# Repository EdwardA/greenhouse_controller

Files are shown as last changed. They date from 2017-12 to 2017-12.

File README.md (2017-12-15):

# greenhouse_controller
Arduino and Linux based sensor and control network
As part of a belated Devember

This project is to design and implement a distributed sensor and control system to automate an indoors growing environment.

As the network is designed to automate high volume growing enviroments. Each growing bed utalises its own slave unit which manages and records the data from that bed while passing the data back to the main controller for logging. While also reciving data back from the controller to control the actuators on that bed.

The system will be designed to be expandable very quickly and easily, by adding new 'beds' to the network.

---Slave board---

--Sensors--
Light (intensity and colour)
soil moisture
Soil temperature
Air temperature
RTC (Real Time Clock)

--Control--
Growing lights (LED, RGB)
Sprinklers (Three per bed)
Emergancy Stop
Heater

--Conectivity--
USB (mainly for debug and programming)
Ethernet (Comunicating with the controller)

---Controller Board---
Recive sensor data from slave boards, and send changes in paramaters back.
Most likely Python script
ROS?
Recive changes in parameters from user and distribute relevant commands to slave units.

The slave unit is based off the ATMEGA 1284 chip, using a 3rd party arduino bootloader.

The slave is programed thanks to the use of the bootloader found here: http://www.leonardomiliani.com/repository/package_leonardomiliani.com_index.json

Light sensor = TCSP3200, code based off the example given at: https://randomnerdtutorials.com/arduino-color-sensor-tcs230-tcs3200/

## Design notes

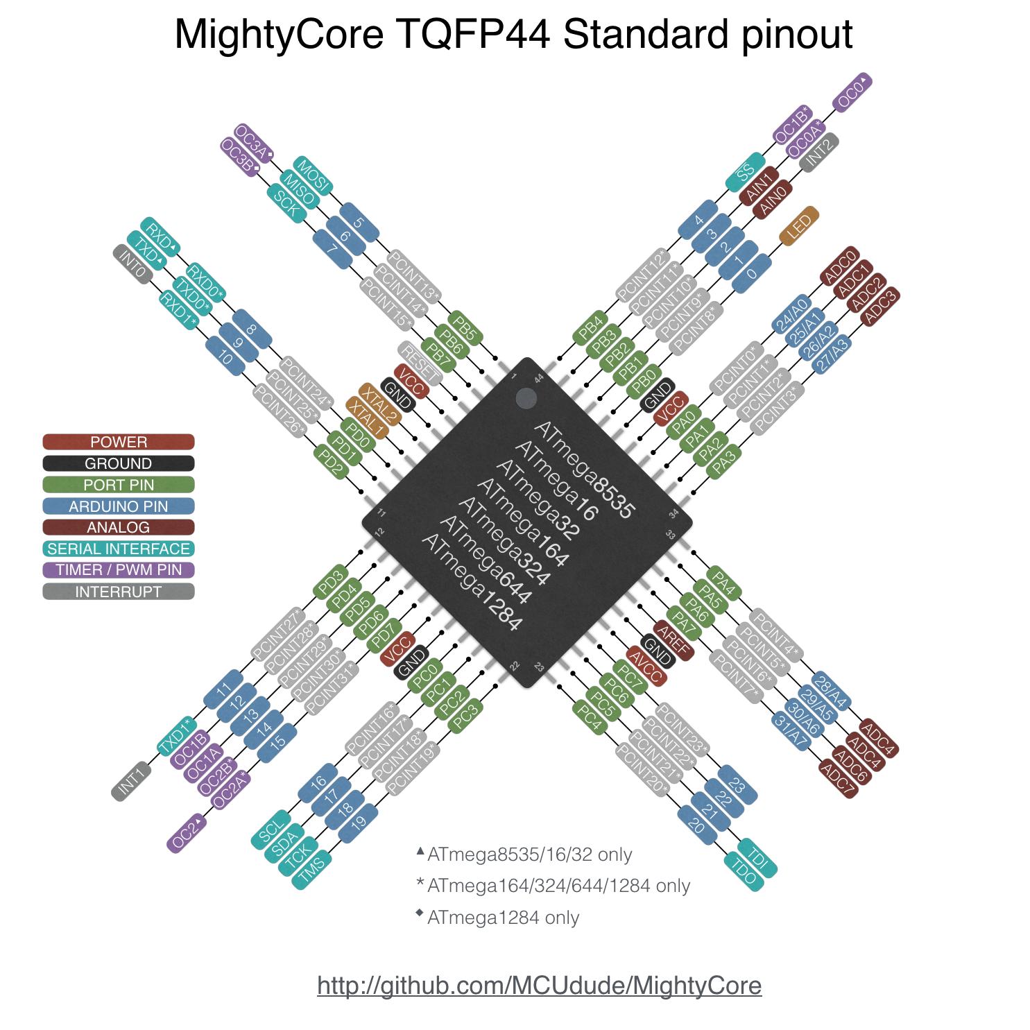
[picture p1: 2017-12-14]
Atmega1284p arduino pinout.png

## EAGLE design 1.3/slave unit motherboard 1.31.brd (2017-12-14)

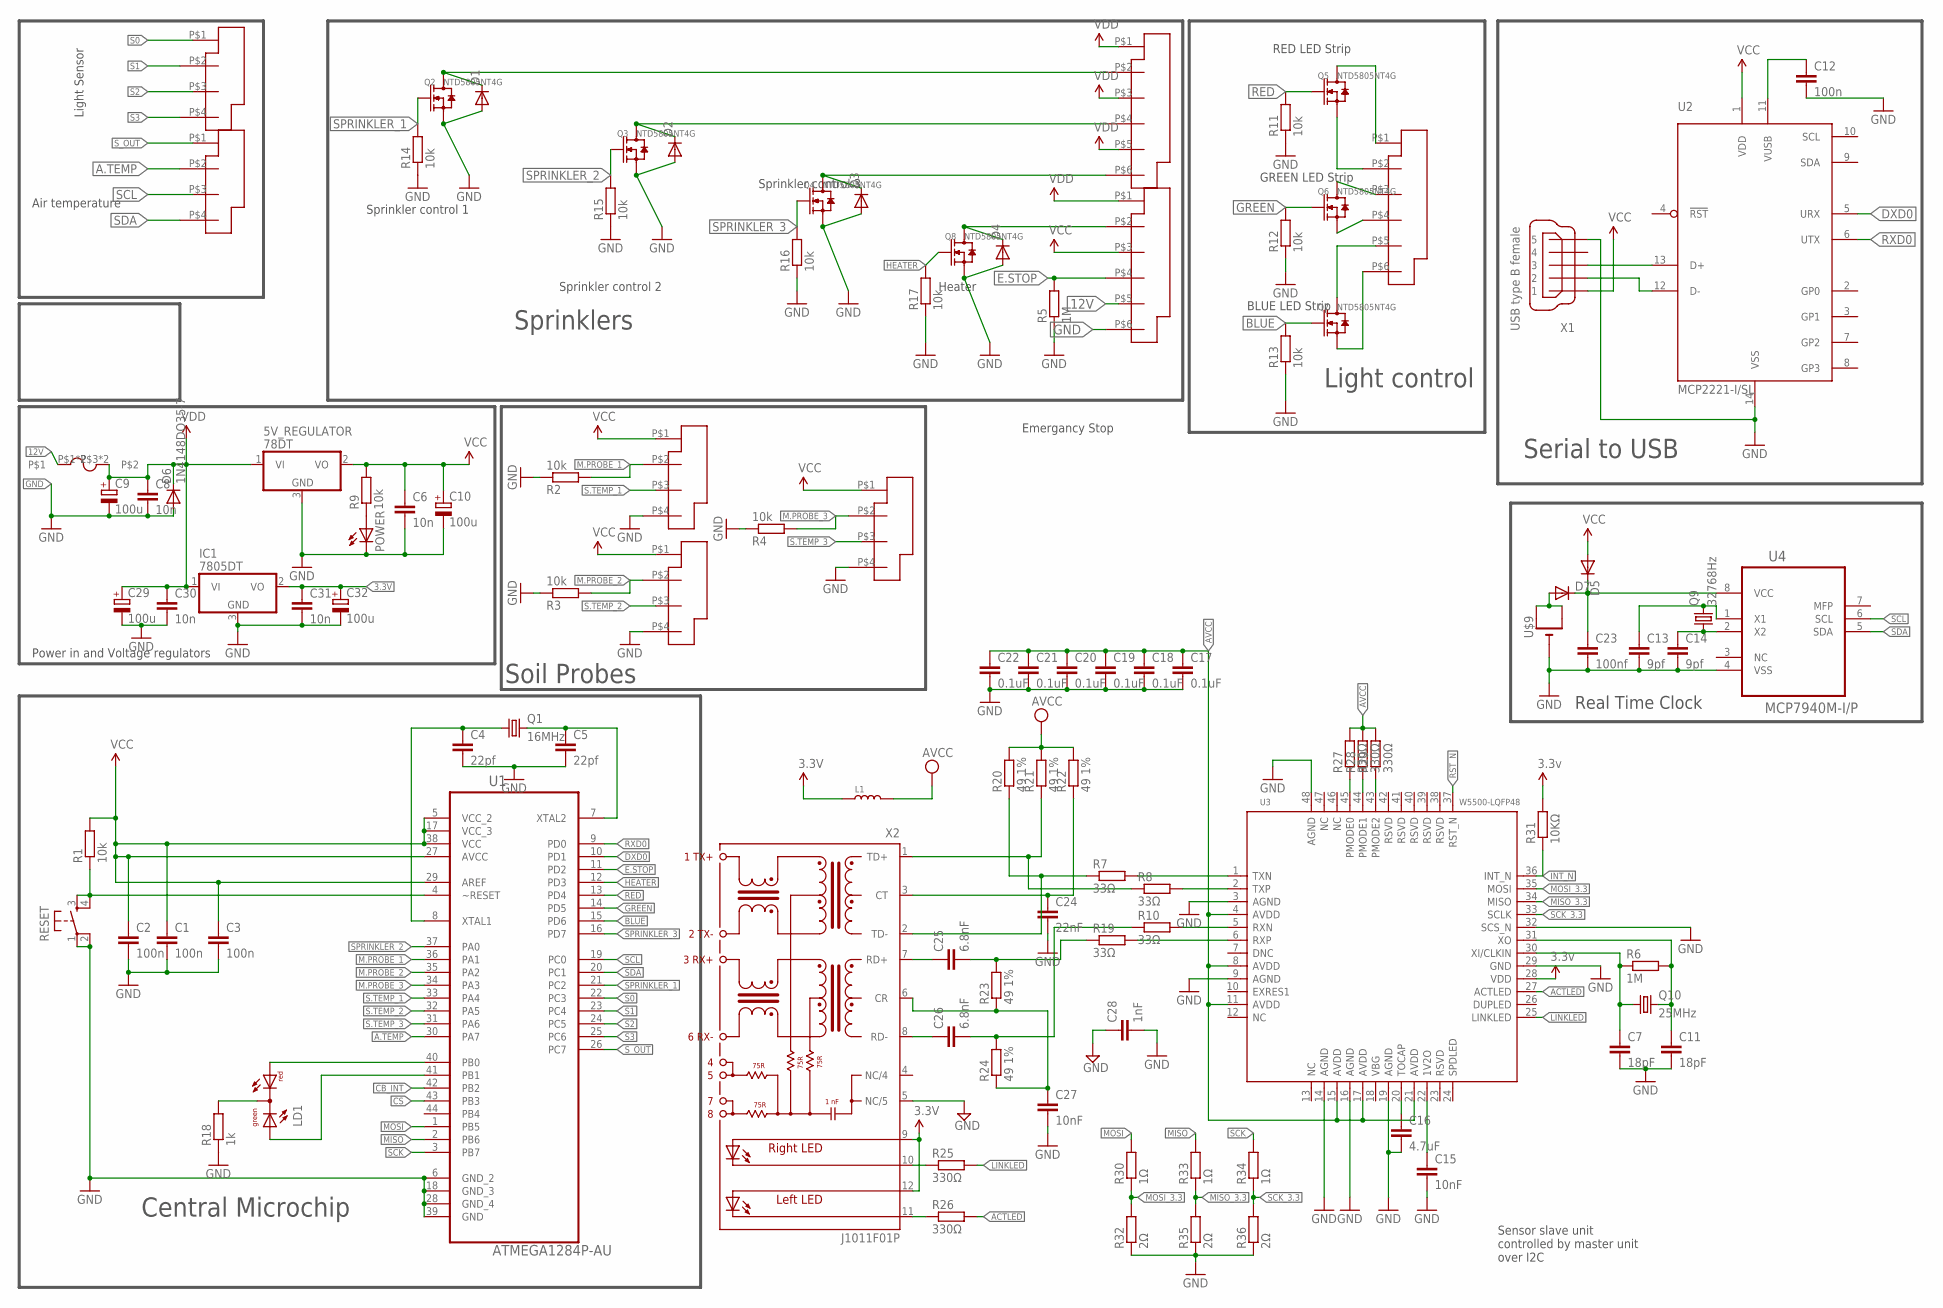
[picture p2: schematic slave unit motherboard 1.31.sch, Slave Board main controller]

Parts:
5V_REGULATOR: 78DT; TO252
C1, C2, C3, C12: 100n; C0805
C4, C5: 22pf; C0805
C6, C8, C30, C31: 10n; C0805
C7, C11: 18pF; C0805
C9, C10, C29, C32: 100u; E1,8-4
C13, C14: 9pf; C025-024X044
C15, C27: 10nF; C0805
C16: 4.7uF; C0805
C17, C18, C19, C20, C21, C22: 0.1uF; C0805
C23: 100nf; C025-024X044
C24: 22nF; C0805
C25, C26: 6.8nF; C0805
C28: 1nF; C0805
D1, D2, D3, D4: DIODE-MINIMELF; MINIMELF
D5, D7: DIODE-D-2.5; D-2.5
D6: 1N4148DO35-7; MINIMELF
IC1: 7805DT; TO252
L1: INDUCTOR/FERRITE-BEAD'0805'; L0805
LD1: DUOLED-RG-C; DUOLED-C-5MM
LEDS1: 3X2TERM; 3*2TERM
POWER: LEDLD260; LD260
Q1: 16MHz; HC49
Q2, Q3, Q4, Q8: NTD5805NT4G; SOT-23
Q5, Q6, Q7: NTD5805NT4G; DPAK
Q9: 32768Hz; TC26V
Q10: 25MHz; HC49
R1, R2, R3, R4, R9, R11, R12, R13, R14, R15, R16, R17: 10k; M0805
R5, R6: 1M; M0805
R7, R8, R10, R19: 33Ω; M0805
R18: 1k; M0805
R20, R21, R22, R23, R24: 49 1%; M0805
R25, R26, R27, R28, R29: 330Ω; M0805
R30, R33, R34: 1Ω; M0805
R31: 10KΩ; M0805
R32, R35, R36: 2Ω; M0805
RESET: TACTILE-SWITCH-PTH; TAC-SWITCH-PTH
U1: ATMEGA1284P-AU; QFP80P1200X1200X120-44N
U2: MCP2221-I/SL; SOIC14
U3: W5500-LQFP48; LQFP48-0.5-7X7MM
U4: MCP7940M-I/P; DIP254P762X508-8P
U$1: 520MM_FUSE_HOLDER; 2.5X5MM_FUSE_HOLDER
U$2, U$3, U$4, U$7, U$8: 2X2TERM
U$5, U$6: 3X2TERM; 3*2TERM
U$9: CR1220-THM
X1: USB type B female; 32005-501
X2: J1011F01P; J1

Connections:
3.3V: C31.1, C32.+, IC1.2 (VO), L1.1, R31.2, U3.28 (VDD), X2.9 (A-R), X2.12 (AL)
12V: U$1.P$1, U$1.P$2, U$5.P$5
A.TEMP: U1.30 (PA7), U$3.P$2
ACTLED: R26.2, U3.27 (ACTLED)
AVCC: C17.1, C18.1, C19.1, C20.1, C21.1, C22.1, L1.2, R20.2, R21.2, R22.2, R27.2, R28.2, R29.2, U3.4 (AVDD), U3.8 (AVDD), U3.11 (AVDD), U3.15 (AVDD), U3.17 (AVDD), U3.21 (AVDD)
BLUE: Q7.1 (G), R13.2, U1.15 (PD6)
CB_INT: U1.42 (PB2)
CS: U1.43 (PB3)
DXD0: U1.10 (PD1), U2.5 (URX)
E.STOP: R5.2, U1.11 (PD2), U$5.P$4
EGND: C28.1, X2.5 (NC/5)
ERROR: LD1.AR, U1.40 (PB0)
GND: 5V_REGULATOR.3 (GND), C1.2, C2.2, C3.2, C4.2, C5.2, C6.2, C7.2, C8.2, C9.-, C10.-, C11.2, C12.2, C13.2, C14.2, C15.2, C16.2, C17.2, C18.2, C19.2, C20.2, C21.2, C22.2, C23.2, C24.2, C27.2, C28.2, C29.-, C30.2, C31.2, C32.-, D1.A, D2.A, D3.A, D4.A, D6.A, IC1.3 (GND), POWER.K (C), Q2.2 (S), Q3.2 (S), Q4.2 (S), Q8.2 (S), R2.1, R3.1, R4.1, R5.1, R11.1, R12.1, R13.1, R14.1, R15.1, R16.1, R17.1, R18.1, R32.1, R35.1, R36.1, RESET.1, RESET.2, U1.6 (GND_2), U1.18 (GND_3), U1.28 (GND_4), U1.39 (GND), U2.14 (VSS), U3.3 (AGND), U3.9 (AGND), U3.14 (AGND), U3.16 (AGND), U3.19 (AGND), U3.29 (GND), U3.48 (AGND), U4.4 (VSS), U$4.P$4, U$5.P$6, U$7.P$4, U$8.P$4, U$9.-, X1.5
GREEN: Q6.1 (G), R12.2, U1.14 (PD5)
HEATER: Q8.1 (G), R17.2, U1.12 (PD3)
INT_N: R31.1, U3.36 (INT_N)
LINKLED: R25.2, U3.25 (LINKLED)
M.PROBE_1: R2.2, U1.36 (PA1), U$4.P$2
M.PROBE_2: R3.2, U1.35 (PA2), U$8.P$2
M.PROBE_3: R4.2, U1.34 (PA3), U$7.P$2
MISO: R33.2, U1.2 (PB6)
MISO_3.3: R33.1, R35.2, U3.34 (MISO)
MOSI: R30.2, U1.1 (PB5)
MOSI_3.3: R30.1, R32.2, U3.35 (MOSI)
unnamed: LEDS1.P$1, Q5.3 (D)
unnamed: U2.13 (D+), X1.3
unnamed: C4.1, Q1.1, U1.8 (XTAL1)
unnamed: C5.1, Q1.2, U1.7 (XTAL2)
unnamed: U2.12 (D-), X1.2
unnamed: C23.1, D5.C, D7.C, U4.8 (VCC)
unnamed: LD1.C, R18.2
unnamed: D7.A, U$9.+1 (+), U$9.+2 (+1)
unnamed: D3.C, Q4.3 (D), U$6.P$6
unnamed: LEDS1.P$2, Q5.2 (S)
unnamed: LEDS1.P$3, Q6.3 (D)
unnamed: LEDS1.P$4, Q6.2 (S)
unnamed: LEDS1.P$5, Q7.3 (D)
unnamed: LEDS1.P$6, Q7.2 (S)
unnamed: C7.1, Q10.1, R6.1, U3.30 (XI/CLKIN)
unnamed: C11.1, Q10.2, R6.2, U3.31 (XO)
unnamed: C15.1, U3.22 (1V2O)
unnamed: D4.C, Q8.3 (D), U$5.P$2
unnamed: C12.1, U2.11 (VUSB)
unnamed: C16.1, U3.20 (TOCAP)
unnamed: R7.2, U3.1 (TXN)
unnamed: R8.2, U3.2 (TXP)
unnamed: R10.2, U3.5 (RXN)
unnamed: R19.2, U3.6 (RXP)
unnamed: R7.1, R20.1, X2.2 (TD-)
unnamed: R8.1, R21.1, X2.1 (TD+)
unnamed: POWER.A, R9.1
unnamed: C26.2, R10.1, R24.2
unnamed: C25.2, R19.1, R23.2
unnamed: C24.1, R22.1, X2.3 (CT)
unnamed: C26.1, X2.8 (RD-)
unnamed: C25.1, X2.7 (RD+)
unnamed: C27.1, R23.1, R24.1, X2.6 (CR)
unnamed: R25.1, X2.10 (C-R)
unnamed: R26.1, X2.11 (C-L)
unnamed: R27.1, U3.45 (PMODE0)
unnamed: R28.1, U3.44 (PMODE1)
unnamed: R29.1, U3.43 (PMODE2)
unnamed: C13.1, Q9.2, U4.1 (X1)
unnamed: C14.1, Q9.1, U4.2 (X2)
RED: Q5.1 (G), R11.2, U1.13 (PD4)
RESET: R1.1, RESET.3, RESET.4, U1.4 (~RESET)
RST_N: U3.37 (RST_N)
RUNNING: LD1.AX (AG), U1.41 (PB1)
RXD0: U1.9 (PD0), U2.6 (UTX)
S0: U1.22 (PC3), U$2.P$1
S1: U1.23 (PC4), U$2.P$2
S2: U1.24 (PC5), U$2.P$3
S3: U1.25 (PC6), U$2.P$4
S.TEMP_1: U1.33 (PA4), U$4.P$3
S.TEMP_2: U1.32 (PA5), U$8.P$3
S.TEMP_3: U1.31 (PA6), U$7.P$3
SCK: R34.2, U1.3 (PB7)
SCK_3.3: R34.1, R36.2, U3.33 (SCLK)
SCL: U1.19 (PC0), U4.6 (SCL), U$3.P$3
SCS_N: U3.32 (SCS_N)
SDA: U1.20 (PC1), U4.5 (SDA), U$3.P$4
SPRINKLER_1: Q2.1 (G), R14.2, U1.21 (PC2)
SPRINKLER_2: Q3.1 (G), R15.2, U1.37 (PA0)
SPRINKLER_3: Q4.1 (G), R16.2, U1.16 (PD7)
SPRINKLER_ONE: D1.C, Q2.3 (D), U$6.P$2
SPRINKLER_TWO: D2.C, Q3.3 (D), U$6.P$4
S_OUT: U1.26 (PC7), U$3.P$1
VCC: 5V_REGULATOR.2 (VO), C1.1, C2.1, C3.1, C6.1, C10.+, D5.A, R1.2, R9.2, U1.5 (VCC_2), U1.17 (VCC_3), U1.27 (AVCC), U1.29 (AREF), U1.38 (VCC), U2.1 (VDD), U$4.P$1, U$5.P$3, U$7.P$1, U$8.P$1, X1.1
VDD: 5V_REGULATOR.1 (VI), C8.1, C9.+, C29.+, C30.1, D6.C, IC1.1 (VI), U$1.P$3, U$1.P$4, U$5.P$1, U$6.P$1, U$6.P$3, U$6.P$5

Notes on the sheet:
Power in and Voltage regulators
Sensor slave unit controlled by master unit over I2C
Serial to USB
Central Microchip
RED LED Strip
GREEN LED Strip
BLUE LED Strip
Light Sensor
Light control
Sprinkler control 1
Sprinkler control 2
Sprinkler control 3
Sprinklers
Soil Probes
Air temperature
Heater
Emergancy Stop
Real Time Clock

Board: 2 copper layers, 107 parts (0 on the bottom side), 85 nets, no tracks yet.

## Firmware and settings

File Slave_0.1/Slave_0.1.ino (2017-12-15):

//Libraries
#include <PID_v1.h>


//---INPUTS---

//Moisture Probes
const int moisture_One = A1;
int moisture_One_Val = 0;
const int moisture_Two = A2;
int moisture_Two_Val = 0;
const int moisture_Three = A3;
int moisture_Three_Val = 0;

//Temperature Sensor
const int temp_One = A4;
int temp_One_Val = 0;
const int temp_Two = A5;
int temp_Two_Val = 0;
const int temp_Three = A6;
int temp_Three_Val = 0;

//Air Temperature Sensor
const int temp_Air = A7;
int temp_Air_Val = 0;

//Light colour sensor
const int S0 = 19;
const int S1 = 20;
const int S2 = 21;
const int S3 = 22;
const int S_Out = 23;

int red_Freq = 0;
int green_Freq = 0;
int blue_Freq = 0;

double red_Colour = 0;
double red_Setpoint = 0;
double green_Colour = 0;
double green_Setpoint = 0;
double blue_Colour = 0;
double blue_Setpoint = 0;


//---OUTPUTS---

//Sprinklers
const int sprinkler_One = 18;
int sprinkler_One_Val = 0;
const int sprinkler_Two = 24;
int sprinkler_Two_Val = 0;
const int sprinkler_Three = 15;
int sprinkler_Three_Val = 0;

//Heater
const int heater = 11;
int heater_Val = 0;

//Emergancy Stop
const int E_Stop = 10;
volatile byte emergancy = LOW;

//RGB LEDs
const int red = 12;
int red_Val = 0;
const int green = 13;
int green_Val = 0;
const int blue = 14;
int blue_Val = 0;

//---OTHER---


double Kp = 0;
double Ki = 0;
double Kd = 0;

PID red_PID(red_Colour, red_Val, red_Setpoint, Kp, Ki, Kd, DIRECT);
PID green_PID(green_Colour, green_Val, green_Setpoint, Kp, Ki, Kd, DIRECT);
PID blue_PID(blue_Colour, blue_Val, blue_Setpoint, Kp, Ki, Kd, DIRECT);


void setup() {
  //Sprinklers
  pinMode(sprinkler_One, OUTPUT);
  pinMode(sprinkler_Two, OUTPUT);
  pinMode(sprinkler_Three, OUTPUT);

  //Heater
  pinMode(heater, OUTPUT);

  //Emergancy Stop
  pinMode(E_Stop,INPUT);
  attachInterrupt(25,emergancy_Stop, LOW);

  //RGB LEDs
  pinMode(red, OUTPUT);
  pinMode(green, OUTPUT);
  pinMode(blue, OUTPUT);

  //Light colour sensor
  pinMode(S0, OUTPUT);
  pinMode(S1, OUTPUT);
  pinMode(S2, OUTPUT);
  pinMode(S3, OUTPUT);
  
  pinMode(S_Out, INPUT);
  
  digitalWrite(S0,HIGH); //sets the frequency scaling to 20%
  digitalWrite(S1,LOW);


  red_PID.SetMode(AUTOMATIC);
  green_PID.SetMode(AUTOMATIC);
  blue_PID.SetMode(AUTOMATIC);
}

void loop() {
  

}

void colour_Check(){
  digitalWrite(S2,LOW); //set sensor to read red value
  digitalWrite(S3,LOW);

  red_Freq = pulseIn(S_Out,LOW); //Read red value
  red_Colour = map(red_Freq, 0,100,255,0); // maps red sensor output to standard RGB range **Change input values to map to within appropriate range after testing**
  delay(100);
  
  digitalWrite(S2,HIGH); //set sensor to read green value
  digitalWrite(S3,HIGH);

  green_Freq = pulseIn(S_Out,LOW); //Read red value
  green_Colour = map(green_Freq, 0,100,255,0); // maps green sensor output to standard RGB range **Change input values to map to within appropriate range after testing**
  delay(100);

  digitalWrite(S2,LOW); //set sensor to read blue value
  digitalWrite(S3,HIGH);

  blue_Freq = pulseIn(S_Out,LOW);
  blue_Colour = map(blue_Freq, 0,100,255,0); // maps blue sensor output to standard RGB range **Change input values to map to within appropriate range after testing**
  delay(100);

  //PID light control

  while (red_Colour != red_Setpoint) {
    red_PID.Compute();
  }
  while (green_Colour != green_Setpoint) {
    green_PID.Compute();
  }
  while (blue_Colour != blue_Setpoint) {
    blue_PID.Compute();
  }
}

void emergancy_Stop(){
  
}

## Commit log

2017-12-14 Added schematic and PCB design files
    1.3 is the current most recent version of the hardware for the slave sensor unit.
    [slave unit motherboard 1.3.brd, slave unit motherboard 1.3.sch, slave unit motherboard 1.31.brd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]
2017-12-14 ATMEGA 1284p arduino pinout added
2017-12-14 Added sprinkler pin constants to ardunio sketch
2017-12-14 Added sensor input constants
2017-12-15 Added all connect pin integers
2017-12-15 Added Light colour sensor code, added link to README and contributed to void setup
2017-12-15 Started adding PID control for the LEDs, however I am having an issue with the syntax for the PID control library.
    [Slave_0.1.ino]

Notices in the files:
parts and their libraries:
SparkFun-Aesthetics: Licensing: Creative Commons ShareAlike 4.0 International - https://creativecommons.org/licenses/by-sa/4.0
